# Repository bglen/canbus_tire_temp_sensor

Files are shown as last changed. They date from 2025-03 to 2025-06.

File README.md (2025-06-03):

# canbus_tire_temp_sensor

Tire temperature sensing with IR sensor arrays and a CAN bus interface

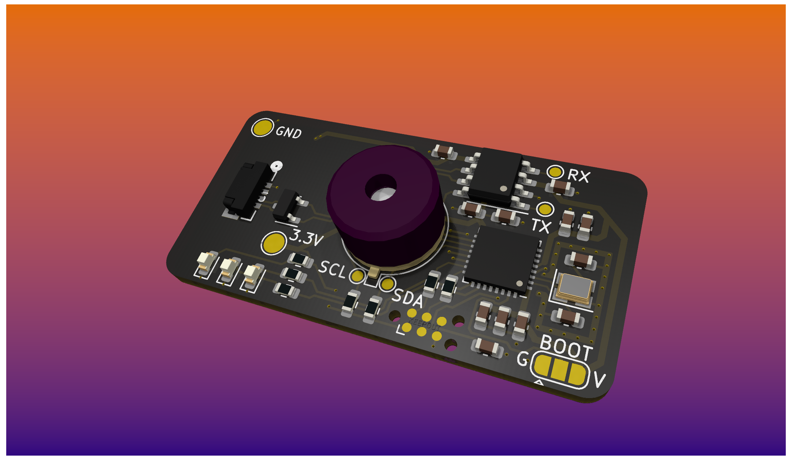
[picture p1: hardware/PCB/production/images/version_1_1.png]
PCB render


### To Do
* CAD enclosure
* CAN Message Data Frame Description
* Firmware
* Adjust PCB design for PCBA

## Building the Hardware
The gerber files for ordering boards can be found in the /production/ folder. A Digikey List for easy BOM ordering can be found [here](https://www.digikey.com/en/mylists/list/VY1O0SBB26).

## Usage
This device outputs thermal camera data to CAN bus. It does not include termination resistors, so only include it at the beginning or end of the network with an external 120 ohm termination resistor.

### Pinout

| Pin Number | Name | Description |
| --- | --- | --- |
| 1 | VCC | Input voltage, 4.5 - 40 VDC |
| 2 | GND | Ground |
| 3 | CAN_N | CAN bus low |
| 4 | CAN_P | CAN bus high |

### Default CAN Message IDs

| Default ID | Message | Description |
| --- | --- | --- |
| 0x700 + 1,2,3  | Data Messages | TBD |
| 0x710 | Config Messages | Adjust Default ID, bitrate, sensor settings |

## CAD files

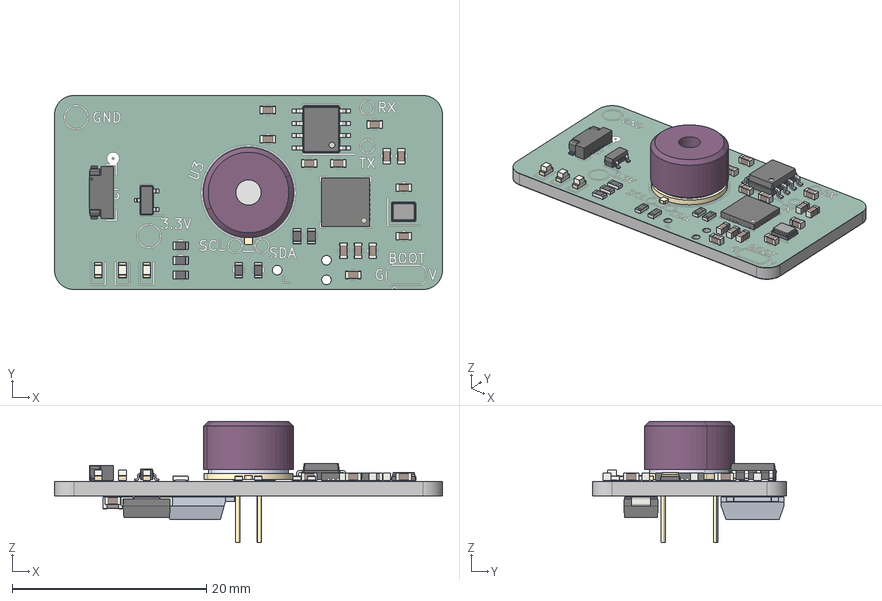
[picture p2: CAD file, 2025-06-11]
hardware/PCB/production/canbus_tire_temp_sensor_v1_3.step
40.0 x 20.0 x 12.5 mm
R_0603_1608Metric x 7
C_0603_1608Metric x 15
LED_0603_1608Metric x 3
molex_zero_hatchi_2147210040
MLX90641ESF-BCA-000-SP
Crystal_SMD_2520-4Pin_2.5x2.0mm
QFN-32-1EP_5x5mm_P0.5mm_EP3.45x3.45mm
SOIC-8_3.9x4.9mm_P1.27mm
SOT-23
canbus_tire_temp_sensor 1.30.1
C_0805_2012Metric
D_SMB
canbus_tire_temp_sensor_silkscreen
canbus_tire_temp_sensor_soldermask
canbus_tire_temp_sensor_PCB

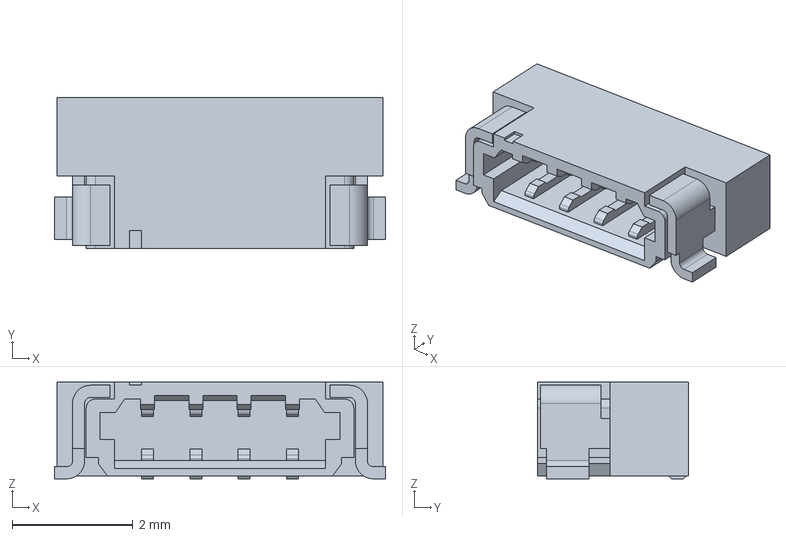
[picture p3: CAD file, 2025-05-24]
hardware/PCB/project_libraries/3d_models/molex_zero_hatchi_2147210040.step
5.48 x 2.50 x 1.60 mm

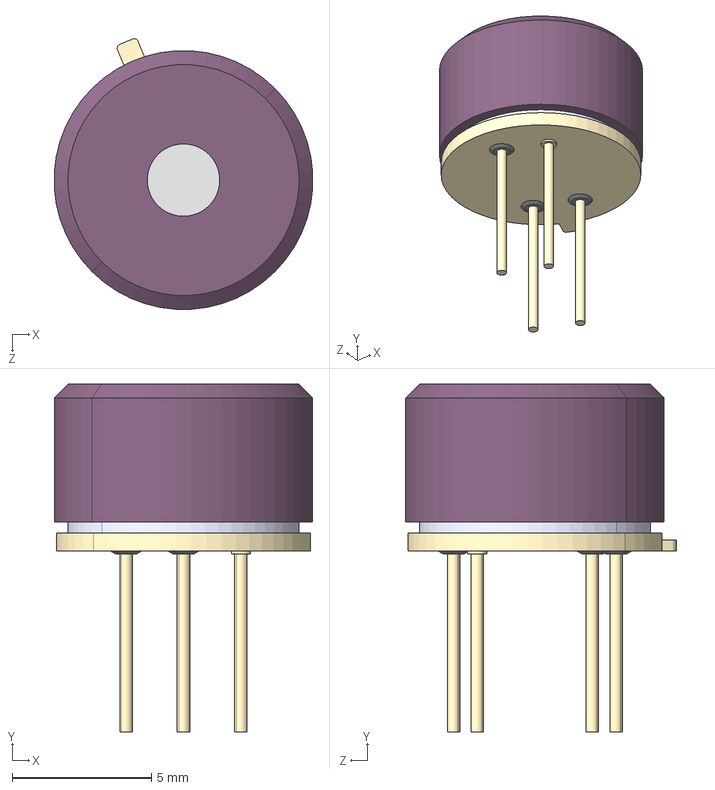
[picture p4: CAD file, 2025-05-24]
hardware/PCB/project_libraries/3d_models/MLX90641ESF-BCA-000-SP.STEP
9.28 x 12.5 x 9.72 mm

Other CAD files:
hardware/PCB/production/canbus_tire_temp_sensor_v1_2.step

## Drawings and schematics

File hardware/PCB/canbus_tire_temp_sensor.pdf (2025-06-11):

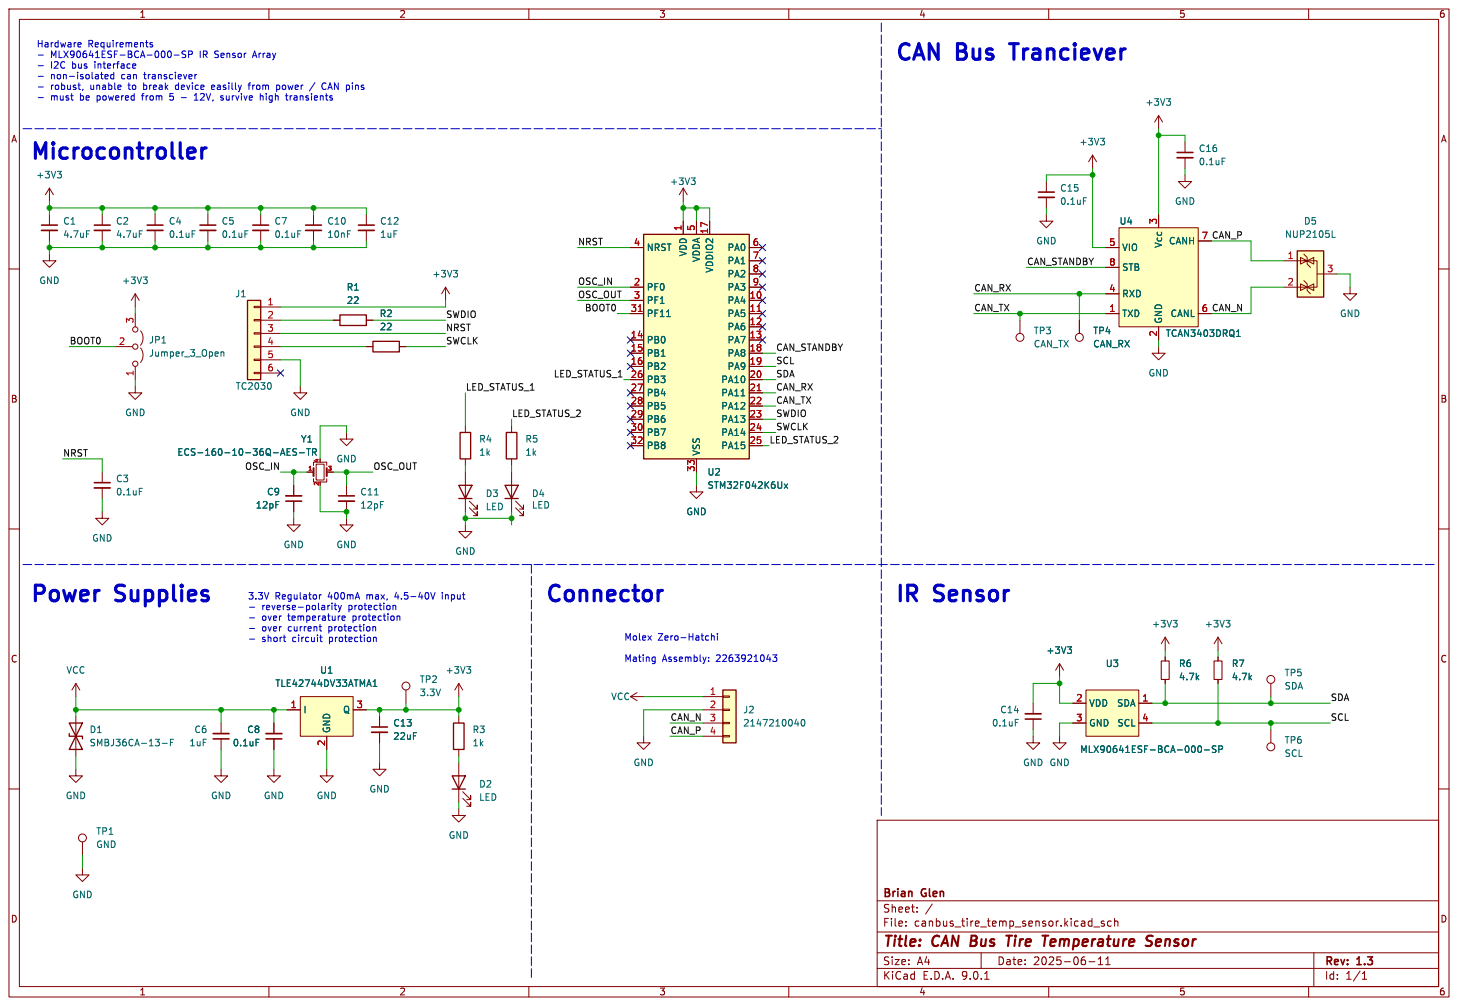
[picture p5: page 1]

Hardware Requirements
- I2C bus interface
- robust, unable to break device easilly from power / CAN pins
Microcontroller

5 VSS 33 VDDIO2 17 PA0 6 PA1 7 PA2 8 PA3 9 PA4 10 PA5 11 PA6 12 PA7 13 PA8 18 PA9 19 PA10 20 PA11 21 PA12 22 PA13 23 PA14 24 PA15 25 U4 TCAN3403DRQ1 VIO 5 STB 8 RXD 4 TXD 1 Vcc 3 GND

Id: 1/1 Title: CAN Bus Tire Temperature Sensor File: canbus_tire_temp_sensor.kicad_sch Sheet: / Brian Glen GND

Molex Zero-Hatchi Mating Assembly: 2263921043

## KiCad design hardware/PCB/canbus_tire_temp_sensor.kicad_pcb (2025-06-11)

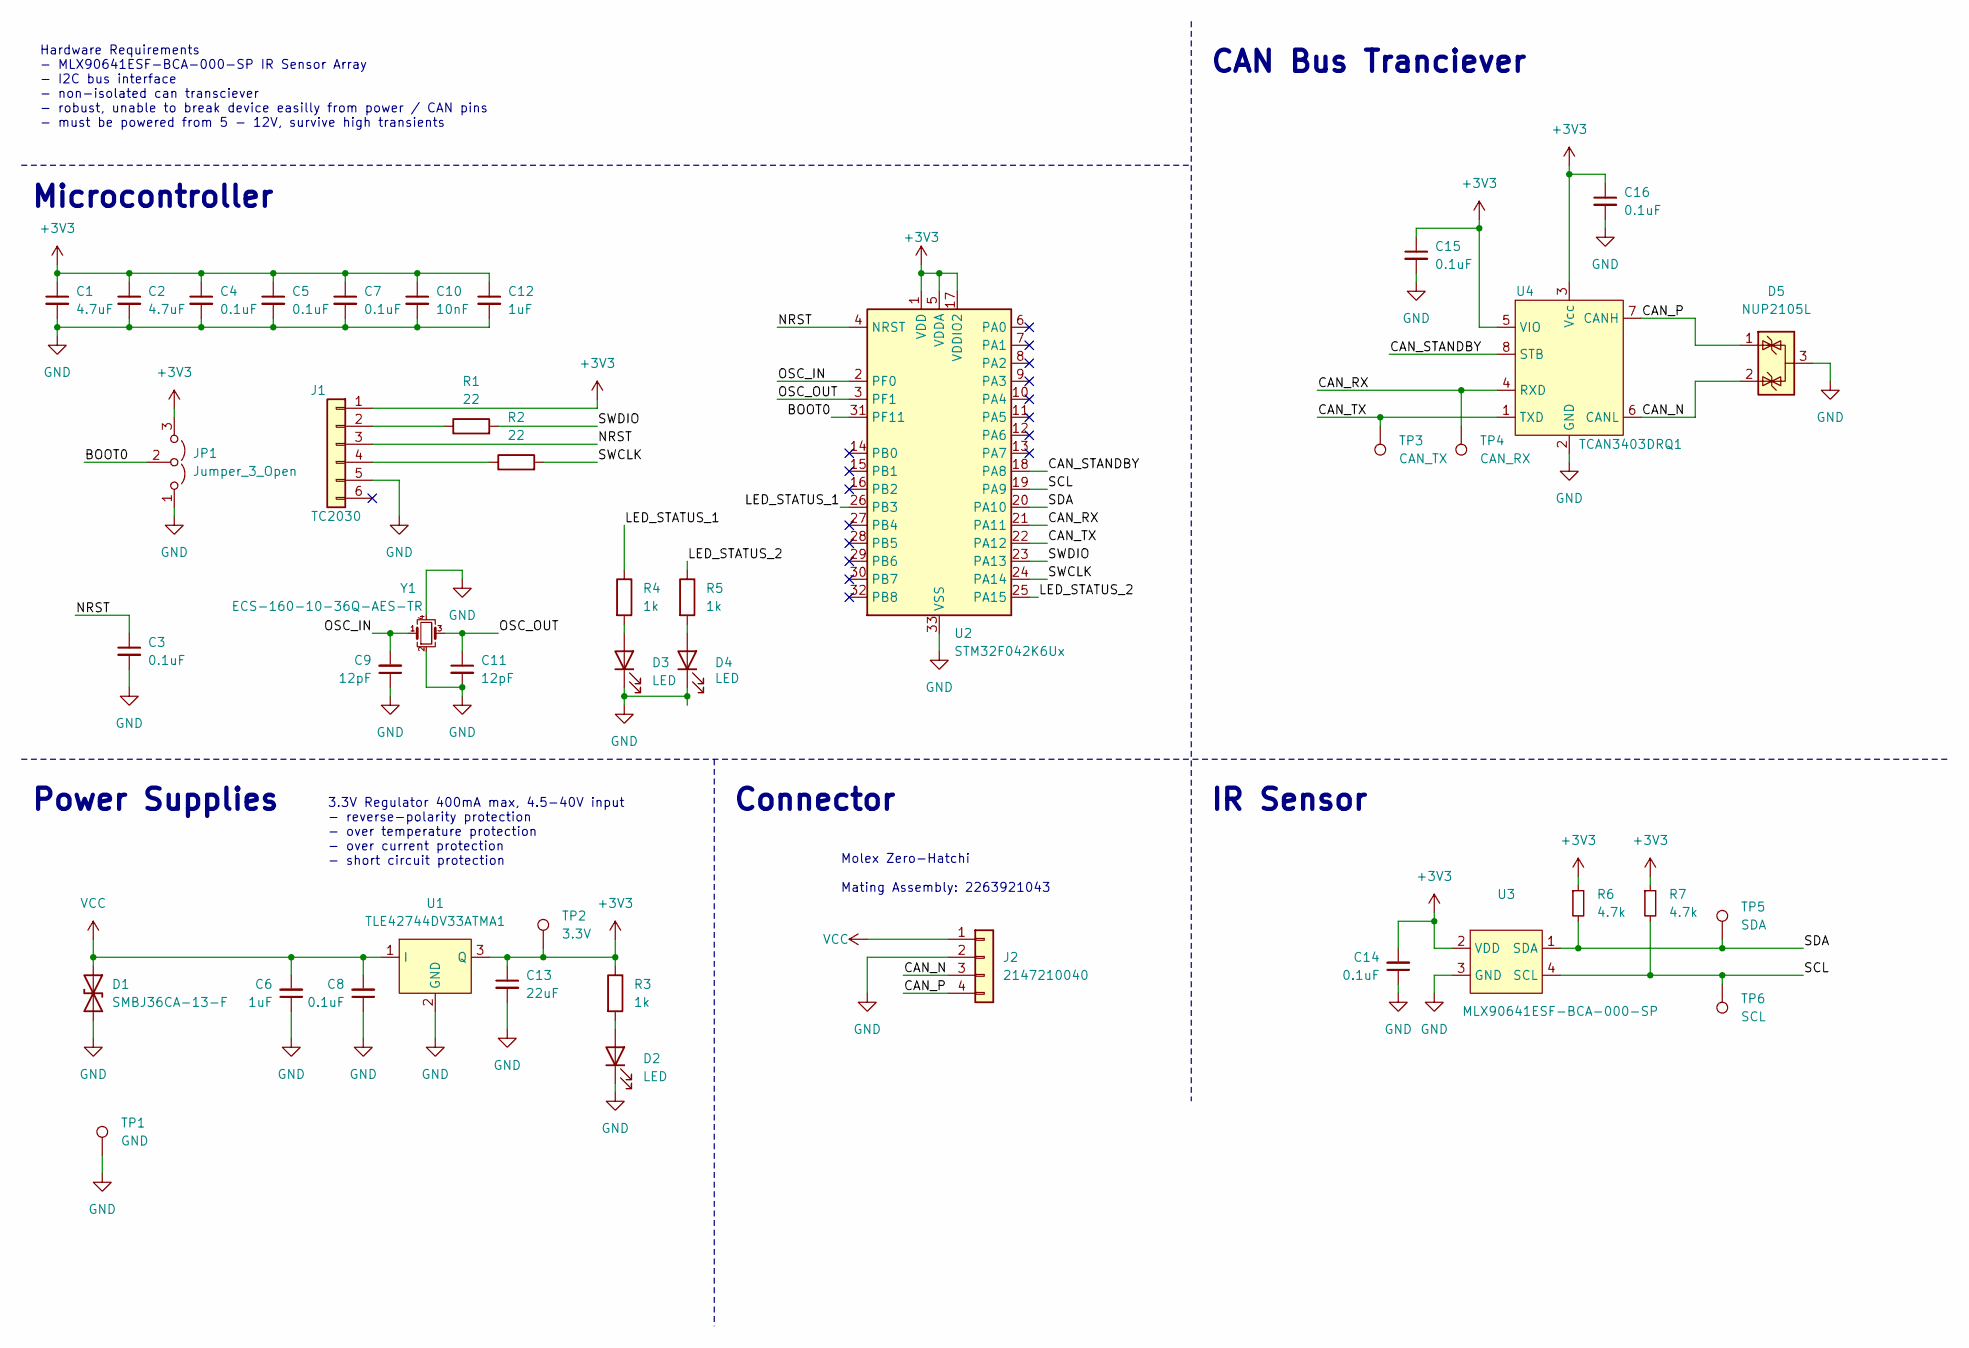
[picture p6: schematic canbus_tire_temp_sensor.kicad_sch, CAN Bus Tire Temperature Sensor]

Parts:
C1, C2: 4.7uF; C_0603_1608Metric
C3, C4, C5, C7, C8, C14, C15, C16: 0.1uF; C_0603_1608Metric
C6, C12: 1uF; C_0603_1608Metric
C9, C11: 12pF; C_0603_1608Metric
C10: 10nF; C_0603_1608Metric
C13: 22uF; C_0805_2012Metric
D1: SMBJ36CA-13-F; D_SMB
D2, D3, D4: LED; LED_0603_1608Metric
D5: NUP2105L; SOT-23
J1: TC2030; Tag-Connect_TC2030-IDC-NL_2x03_P1.27mm_Vertical
J2: 2147210040; Molex_Zero_Hatchi_2147210040
JP1: Jumper_3_Open; SolderJumper-3_P1.3mm_Open_RoundedPad1.0x1.5mm
R1, R2: 22; R_0603_1608Metric
R3, R4, R5: 1k; R_0603_1608Metric
R6, R7: 4.7k; R_0603_1608Metric
TP1: GND; TestPoint_Pad_D2.0mm
TP2: 3.3V; TestPoint_Pad_D2.0mm
TP3: CAN_TX; TestPoint_Pad_D1.0mm
TP4: CAN_RX; TestPoint_Pad_D1.0mm
TP5: SDA; TestPoint_Pad_D1.0mm
TP6: SCL; TestPoint_Pad_D1.0mm
U1: TLE42744DV33ATMA1; TO-252-3_TabPin2
U2: STM32F042K6Ux; QFN-32-1EP_5x5mm_P0.5mm_EP3.45x3.45mm
U3: MLX90641ESF-BCA-000-SP; MLX90641
U4: TCAN3403DRQ1; SOIC-8_3.9x4.9mm_P1.27mm
Y1: ECS-160-10-36Q-AES-TR; Crystal_SMD_2520-4Pin_2.5x2.0mm

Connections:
+3V3: C1.1, C2.1, C4.1, C5.1, C7.1, C10.1, C12.1, C13.1, C14.2, C15.1, C16.1, J1.1, JP1.3 (B), R3.1, R6.1, R7.1, TP2.1, U1.3 (Q), U2.1 (VDD), U2.5 (VDDA), U2.17 (VDDIO2), U3.2 (VDD), U4.3 (Vcc), U4.5 (VIO)
/BOOT0: JP1.2 (C), U2.31 (PF11)
/CAN_N: D5.2 (K), J2.3, U4.6 (CANL)
/CAN_P: D5.1 (K), J2.4, U4.7 (CANH)
/CAN_RX: TP4.1, U2.21 (PA11), U4.4 (RXD)
/CAN_STANDBY: U2.18 (PA8), U4.8 (STB)
/CAN_TX: TP3.1, U2.22 (PA12), U4.1 (TXD)
/LED_STATUS_1: R4.1, U2.26 (PB3)
/LED_STATUS_2: R5.1, U2.25 (PA15)
/NRST: C3.1, J1.3, U2.4 (NRST)
/OSC_IN: C9.2, U2.2 (PF0), Y1.1
/OSC_OUT: C11.1, U2.3 (PF1), Y1.3
/SCL: R7.2, TP6.1, U2.19 (PA9), U3.4 (SCL)
/SDA: R6.2, TP5.1, U2.20 (PA10), U3.1 (SDA)
/SWCLK: R2.2, U2.24 (PA14)
/SWDIO: R1.2, U2.23 (PA13)
GND: C1.2, C2.2, C3.2, C4.2, C5.2, C6.1, C7.2, C8.1, C9.1, C10.2, C11.2, C12.2, C13.2, C14.1, C15.2, C16.2, D1.2 (A2), D2.1 (K), D3.1 (K), D4.1 (K), D5.3 (A), J1.5, J2.2, JP1.1 (A), TP1.1, U1.2 (GND), U2.33 (VSS), U3.3 (GND), U4.2 (GND), Y1.2, Y1.4
unnamed: D2.2 (A), R3.2
unnamed: D3.2 (A), R4.2
unnamed: D4.2 (A), R5.2
unnamed: J1.2, R1.1
unnamed: J1.4, R2.1
VCC: C6.2, C8.2, D1.1 (A1), J2.1, U1.1 (I)

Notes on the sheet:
Power Supplies
3.3V Regulator 400mA max, 4.5-40V input - reverse-polarity protection - over temperature protection - over current protection - short circuit protection
Connector
Hardware Requirements - MLX90641ESF-BCA-000-SP IR Sensor Array - I2C bus interface - non-isolated can transciever - robust, unable to break device easilly from power / CAN pins - must be powered from 5 - 12V, survive high transients
Molex Zero-Hatchi Mating Assembly: 2263921043
CAN Bus Tranciever
IR Sensor
Microcontroller

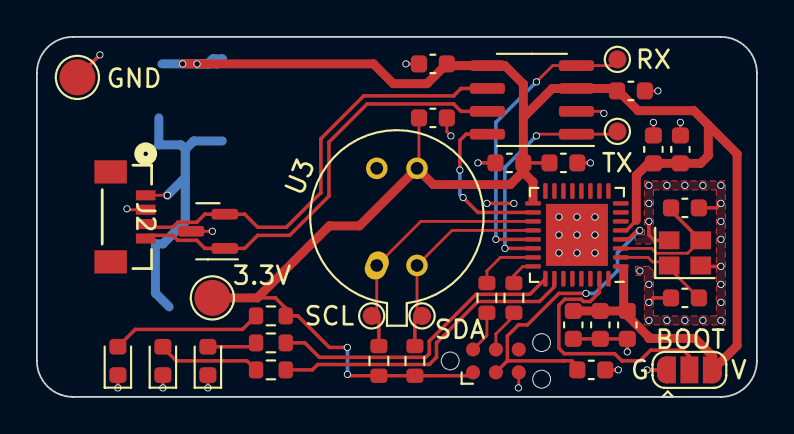
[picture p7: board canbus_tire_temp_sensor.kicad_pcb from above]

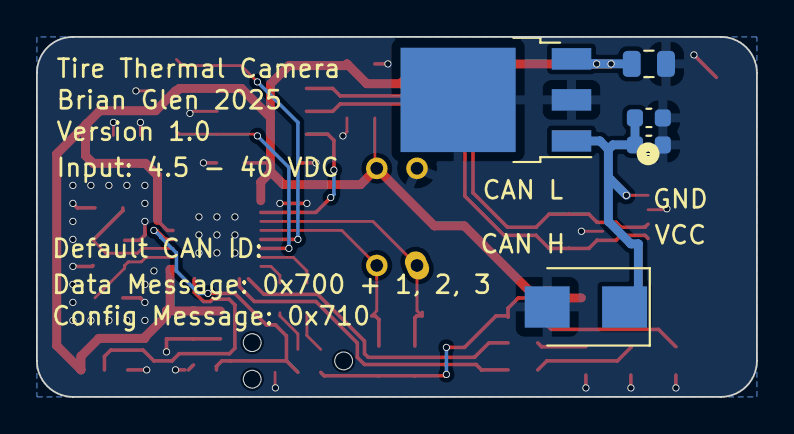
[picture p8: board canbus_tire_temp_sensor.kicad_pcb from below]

Board: 2 copper layers, 40.0 x 20.0 mm, 42 parts (5 on the bottom side), 23 nets.

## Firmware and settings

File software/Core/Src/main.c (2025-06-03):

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
/* Includes ------------------------------------------------------------------*/
#include "main.h"

/* USER CODE BEGIN Includes */

#include "can.h"
/* USER CODE END Includes */

CAN_HandleTypeDef hcan;

I2C_HandleTypeDef hi2c1;

void SystemClock_Config(void);
static void MX_GPIO_Init(void);
static void MX_CAN_Init(void);
static void MX_I2C1_Init(void);
/**
  * @brief  The application entry point.
  * @retval int
  */
int main(void)
{

  /* MCU Configuration--------------------------------------------------------*/

  /* Reset of all peripherals, Initializes the Flash interface and the Systick. */
  HAL_Init();

  /* Configure the system clock */
  SystemClock_Config();

  /* Initialize all configured peripherals */
  MX_GPIO_Init();
  MX_CAN_Init();
  MX_I2C1_Init();
  /* USER CODE BEGIN 2 */

  /* Initialize CAN application module */
  if (CANAPP_Init(CAN_DEFAULT_BASE_ID, 1000000) != HAL_OK)
  {
    Error_Handler();
  }

  /* USER CODE END 2 */
  /* USER CODE BEGIN WHILE */
  while (1)
  {
    /* USER CODE END WHILE */

    /* USER CODE BEGIN 3 */
    static uint32_t lastTx = 0;
    uint8_t data[8] = {0};

    if (HAL_GetTick() - lastTx >= 100)
    {
      uint32_t base = CANAPP_GetBaseID();
      CANAPP_Send(base + 1, data, 8);
      CANAPP_Send(base + 2, data, 8);
      CANAPP_Send(base + 3, data, 8);
      CANAPP_Send(base + 4, data, 8);
      lastTx = HAL_GetTick();
    }

    CAN_RxHeaderTypeDef rxHeader;
    uint8_t rxData[8];
    if (CANAPP_Receive(&rxHeader, rxData) == HAL_OK)
    {
      if (rxHeader.StdId == CAN_CONFIG_MSG_ID && rxHeader.DLC >= 6)
      {
        uint32_t newBase = (rxData[0] << 8) | rxData[1];
        uint32_t newBaud = (rxData[2] << 24) | (rxData[3] << 16) |
                            (rxData[4] << 8) | rxData[5];
        CANAPP_UpdateConfig(newBase, newBaud);
      }
    }
  }
  /* USER CODE END 3 */
}

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


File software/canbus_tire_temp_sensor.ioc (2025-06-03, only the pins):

Mcu.UserName=STM32F042K6Ux
PA10.Signal=I2C1_SDA
PA11.Signal=CAN_RX
PA12.Signal=CAN_TX
PA13.Signal=SYS_SWDIO
PA14.Signal=SYS_SWCLK
PA15.GPIO_Label=LED_STATUS_2
PA15.Signal=GPIO_Output
PA8.GPIO_Label=CAN_STANDBY
PA8.Signal=GPIO_Input
PA9.Signal=I2C1_SCL
PB3.GPIO_Label=LED_STATUS_1
PB3.Signal=GPIO_Output
PF0-OSC_IN.Signal=RCC_OSC_IN
PF1-OSC_OUT.Signal=RCC_OSC_OUT

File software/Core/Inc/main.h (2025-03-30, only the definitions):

#define CAN_STANDBY_Pin GPIO_PIN_13
#define CAN_STANDBY_GPIO_Port GPIOA
#define LED_STATUS_2_Pin GPIO_PIN_15
#define LED_STATUS_2_GPIO_Port GPIOA
#define LED_STATUS_1_Pin GPIO_PIN_3
#define LED_STATUS_1_GPIO_Port GPIOB

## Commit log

2025-03-30 Initial STM32 Project
    Pin configuration
2025-03-30 Initial Schematic
    [canbus_tire_temp_sensor.kicad_sch]
2025-03-30 Updated footprints and ref designators
    [canbus_tire_temp_sensor.kicad_sch]
2025-03-30 initial component placement
    [canbus_tire_temp_sensor.kicad_pcb, canbus_tire_temp_sensor.kicad_sch]
2025-05-21 Initial board layout
    [canbus_tire_temp_sensor.kicad_pcb, canbus_tire_temp_sensor.kicad_sch]
2025-05-21 gerbers version 1.0
    [canbus_tire_temp_sensor.kicad_pcb]
2025-05-24 Updated connector, fixed MLX footprint
    [2147210040.stp, MLX90641ESF-BCA-000-SP.STEP, canbus_tire_temp_sensor.kicad_pcb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]
2025-05-24 Rendering, removed old 3d files
    [2147210040.stp, canbus_tire_temp_sensor.kicad_pcb, molex_0430450423.step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]
2025-05-26 Updated schematic to rev 1.1
2025-06-03 version 1.2 - fixed IR sensor footprint
    [canbus_tire_temp_sensor.kicad_pcb, canbus_tire_temp_sensor.step]
2025-06-03 Updated README, cleaned out prod files
    [canbus_tire_temp_sensor.step, canbus_tire_temp_sensor_v1_2.step]
2025-06-03 Updated config for board changes
2025-06-03 Fix CAN bus pin descriptions
2025-06-03 Fix CAN send limit and remove redundant comment
    [can.c, main.c]
2025-06-03 Add documentation comments to MLX90641 driver
2025-06-11 V1.3 - Updated for cheaper JLCPCB options
    Changed via size to most common
    [canbus_tire_temp_sensor.kicad_pcb, canbus_tire_temp_sensor.kicad_sch, canbus_tire_temp_sensor_v1_3.step]

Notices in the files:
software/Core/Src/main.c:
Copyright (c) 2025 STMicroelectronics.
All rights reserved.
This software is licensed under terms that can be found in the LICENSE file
